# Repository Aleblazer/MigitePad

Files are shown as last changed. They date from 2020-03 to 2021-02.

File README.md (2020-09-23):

# MigitePad
## *__MigitePad!__* A Numpad/Nav Cluster with QMK Firmware/Kailh Hotswap/OLED/Rotary Encoder! 
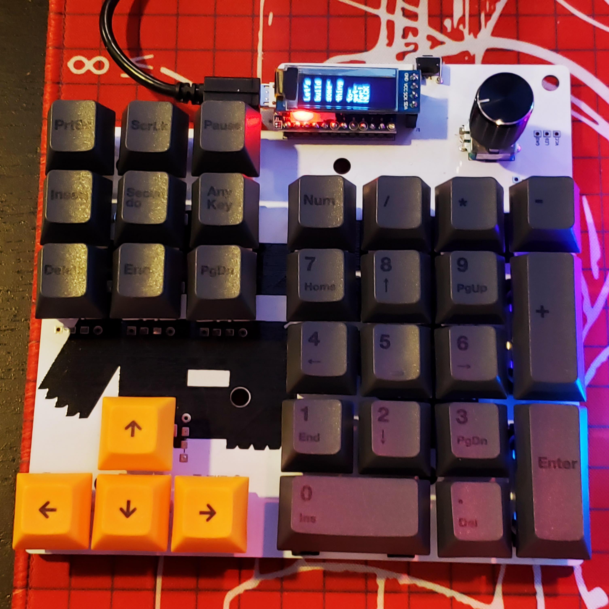
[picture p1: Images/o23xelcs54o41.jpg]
Built Board

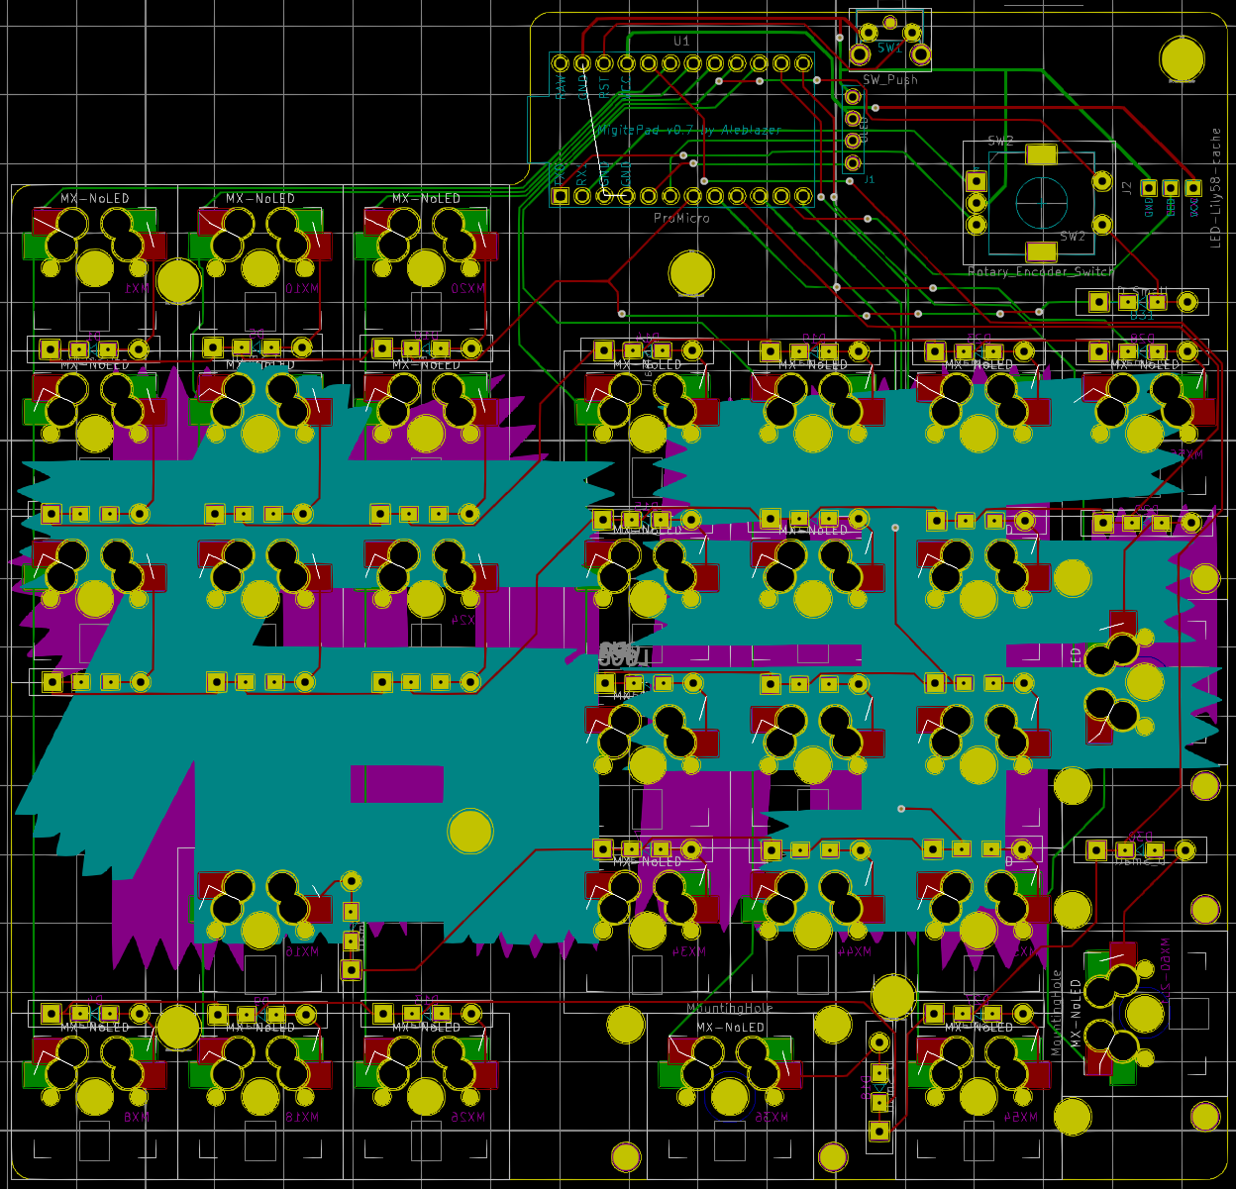
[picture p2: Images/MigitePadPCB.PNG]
PCB

Even reversable for you crazies who want a backwards Numpad!*
*OLED will need to be trace cut and bodged if you want it to work backwards

Materials needed:
* 30x Kailh Hotswap Sockets (Technically optional, hotswap through holes are plated)
* 31x 1N4148 or SOD-123F Diodes
* 30x MX style switches
* 1x MJTP1117 Reset Switch
* 1x Pro Micro or equivilant (Pro Micro chip side up for normal orientation, bottom side up for reversed.)
* 3x 2u stabilizers
* 1x EC11 Rotary Encoder
* 1x SSD1306 OLED (Optional)

For the 3D Printable Case:
* 6x 6mm M2 standoffs
* 12x M2 4mm or 5mm screws

OLED and Rotary Encoder code would need to be added to the end of your keymap.c. Still working on a more official OLED config. Example code borrowed and tested as working from the RoMac+, and is located in "QMK Keyboard Folder/migitepad/keymaps/default/keymap.c". Also encluded a default hex file in the QMK Keyboard Folder.

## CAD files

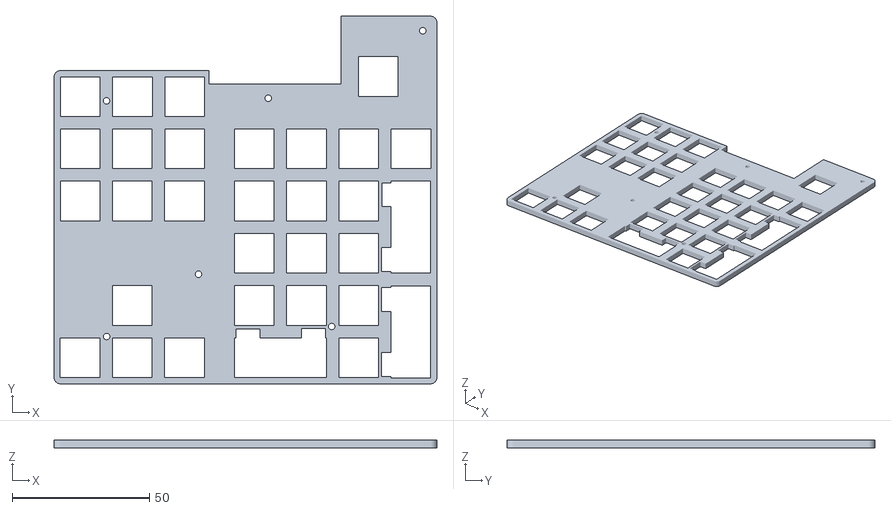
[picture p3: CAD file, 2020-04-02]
3D Printable Plate Files/MigitePad Top Plate v3.stl
139.7 x 134.1 x 3.00

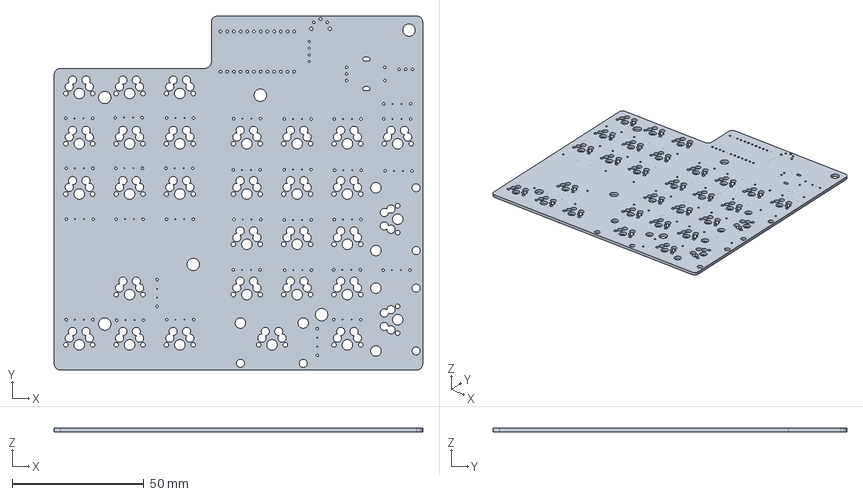
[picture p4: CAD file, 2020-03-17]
MigitePad.step
139.7 x 134.1 x 1.60 mm

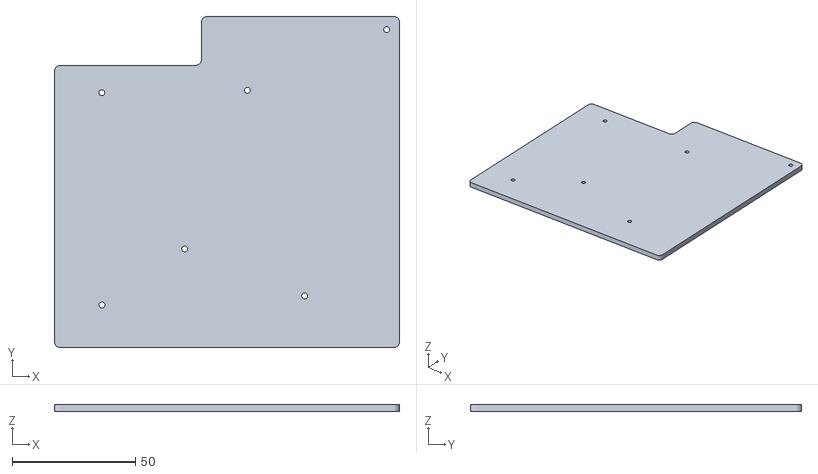
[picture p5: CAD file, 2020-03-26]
3D Printable Plate Files/MigitePad Bottom Plate.stl
139.7 x 134.1 x 3.00

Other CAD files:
3D Printable Plate Files/MigitePad Top Plate v2.stl
MigitePad.stl

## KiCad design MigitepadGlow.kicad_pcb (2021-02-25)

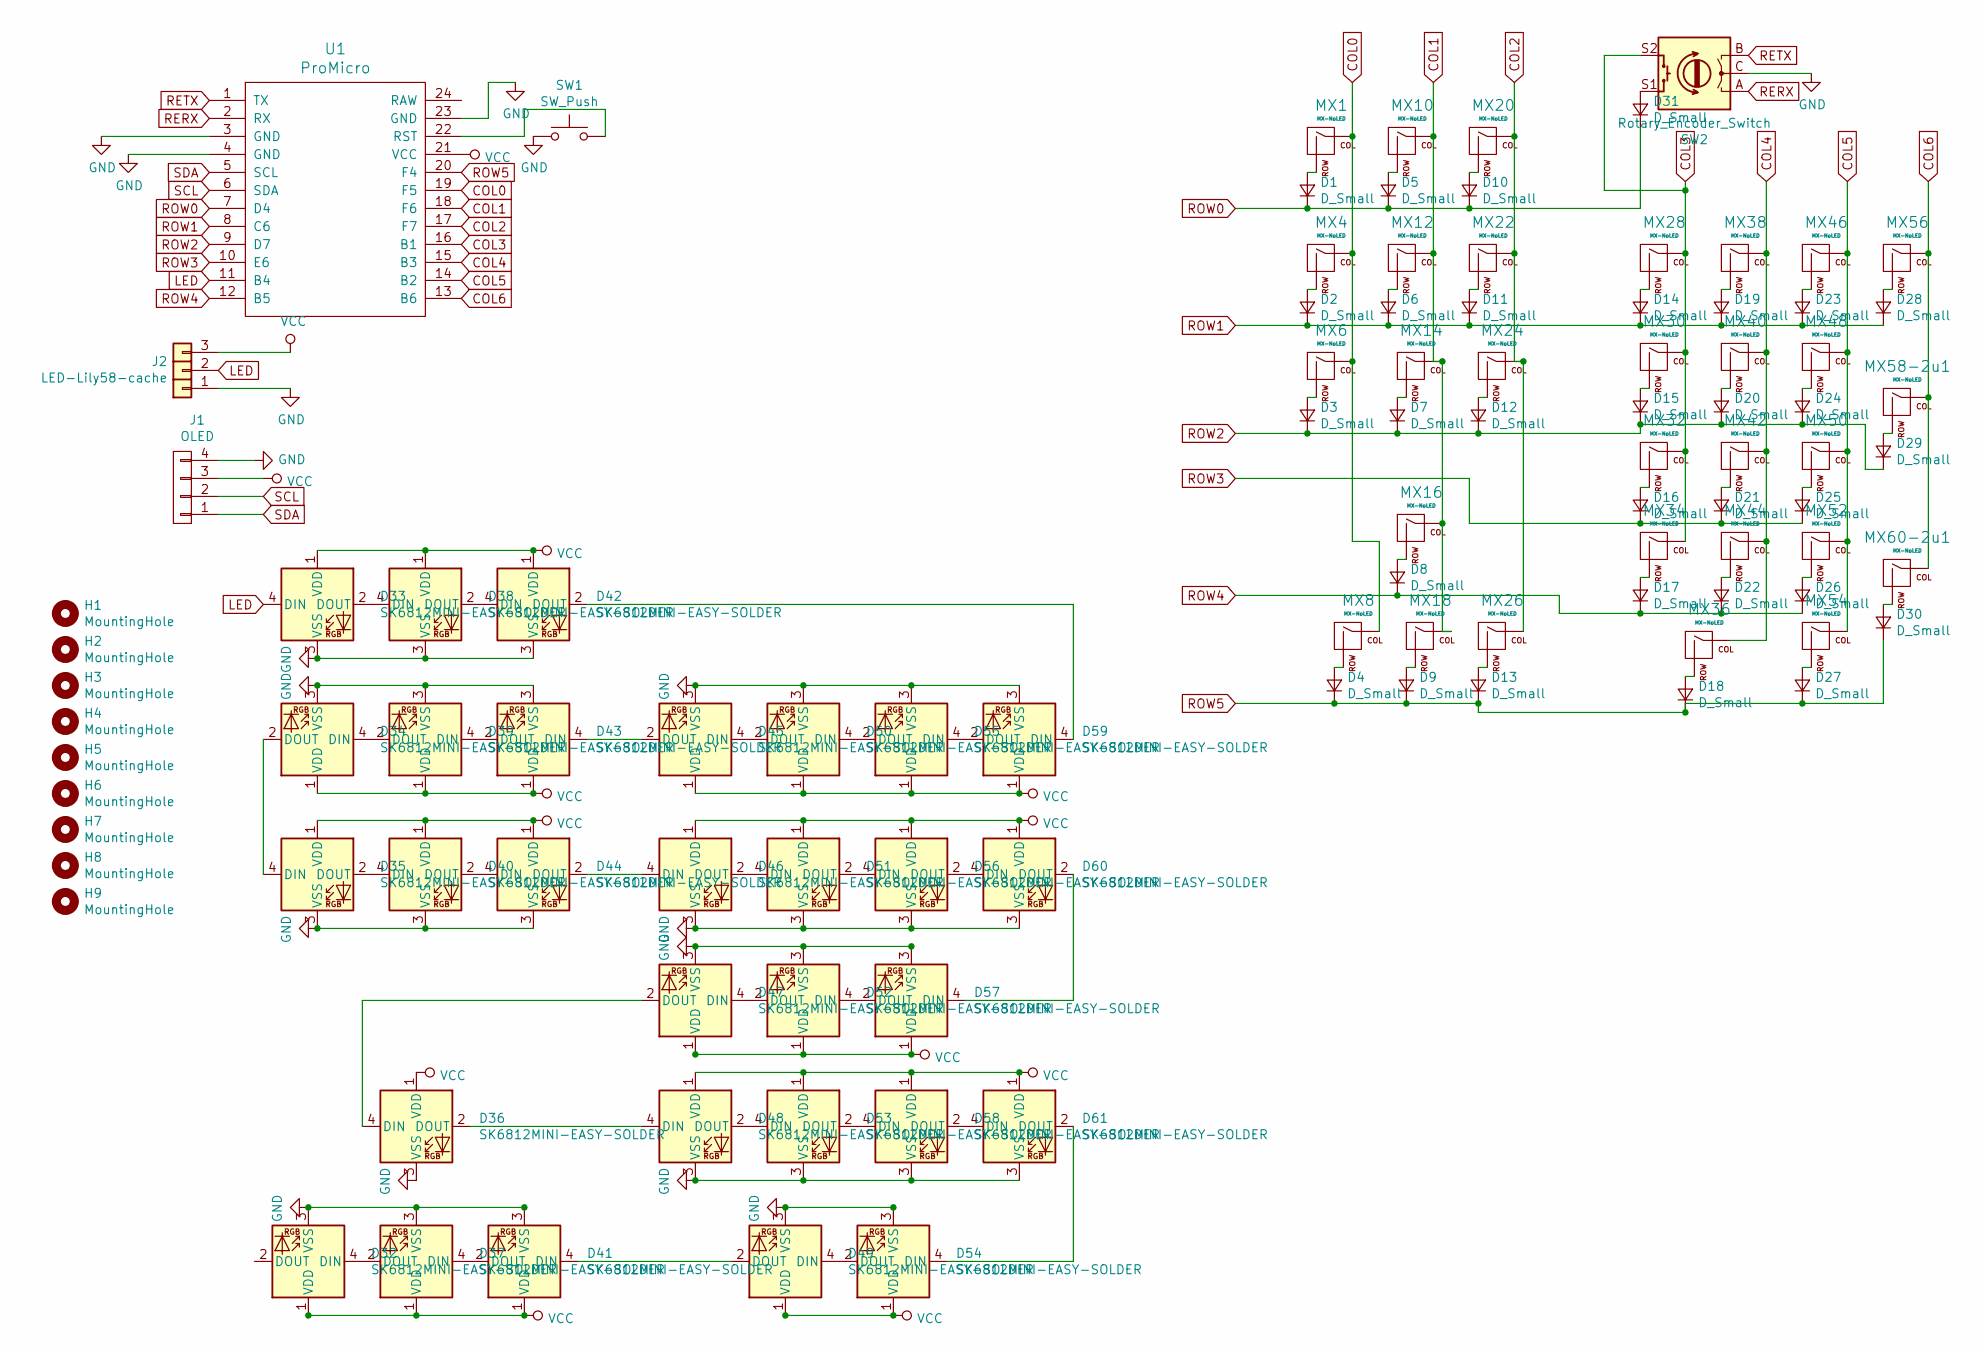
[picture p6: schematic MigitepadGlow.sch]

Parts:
D1, D2, D3, D4, D5, D6, D7, D8, D9, D10, D11, D12, D13, D14, D15, D16, D17, D18, D19, D20, D21, D22, D23, D24, D25, D26, D27, D28, D29, D30, D31: D_Small; Diode_TH_SOD123
D32, D33, D34, D35, D36, D37, D38, D39, D40, D41, D42, D43, D44, D45, D46, D47, D48, D49, D50, D51, D52, D53, D54, D55, D56, D57, D58, D59, D60, D61: SK6812MINI-EASY-SOLDER; YS-SK6812MINI-E
H1, H2, H3: MountingHole; Stabilizer_MX_2u
H4, H5, H6, H7, H8, H9: MountingHole; HOLE_M2_TH
J1: OLED; MY_SIL-4
J2: LED-Lily58-cache; LED
MX1, MX4, MX6, MX8, MX10, MX12, MX14, MX16, MX18, MX20, MX22, MX24, MX26, MX28, MX30, MX32, MX34, MX36, MX38, MX40, MX42, MX44, MX46, MX48, MX50, MX52, MX54, MX56, MX58-2u1, MX60-2u1: MX-NoLED; MXOnly-1U-Hotswap-Double-noled
SW1: SW_Push; SW_Tactile_SPST_Angled_MJTP1117
SW2: Rotary_Encoder_Switch; RotaryEncoder_EC11
U1: ProMicro

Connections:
COL0: MX1.1 (COL), MX4.1 (COL), MX6.1 (COL), MX8.1 (COL), U1.19 (F5)
COL1: MX10.1 (COL), MX12.1 (COL), MX14.1 (COL), MX16.1 (COL), MX18.1 (COL), U1.18 (F6)
COL2: MX20.1 (COL), MX22.1 (COL), MX24.1 (COL), MX26.1 (COL), U1.17 (F7)
COL3: MX28.1 (COL), MX30.1 (COL), MX32.1 (COL), MX34.1 (COL), SW2.S2, U1.16 (B1)
COL4: MX36.1 (COL), MX38.1 (COL), MX40.1 (COL), MX42.1 (COL), MX44.1 (COL), U1.15 (B3)
COL5: MX46.1 (COL), MX48.1 (COL), MX50.1 (COL), MX52.1 (COL), MX54.1 (COL), U1.14 (B2)
COL6: MX56.1 (COL), MX58-2u1.1 (COL), MX60-2u1.1 (COL), U1.13 (B6)
GND: D32.3 (VSS), D33.3 (VSS), D34.3 (VSS), D35.3 (VSS), D36.3 (VSS), D37.3 (VSS), D38.3 (VSS), D39.3 (VSS), D40.3 (VSS), D41.3 (VSS), D42.3 (VSS), D43.3 (VSS), D44.3 (VSS), D45.3 (VSS), D46.3 (VSS), D47.3 (VSS), D48.3 (VSS), D49.3 (VSS), D50.3 (VSS), D51.3 (VSS), D52.3 (VSS), D53.3 (VSS), D54.3 (VSS), D55.3 (VSS), D56.3 (VSS), D57.3 (VSS), D58.3 (VSS), D59.3 (VSS), D60.3 (VSS), D61.3 (VSS), J1.4, J2.1, SW1.1, SW2.C, U1.3 (GND), U1.4 (GND), U1.23 (GND)
LED: D33.4 (DIN), J2.2, U1.11 (B4)
unnamed: D1.2 (A), MX1.2 (ROW)
unnamed: D2.2 (A), MX4.2 (ROW)
unnamed: D3.2 (A), MX6.2 (ROW)
unnamed: D4.2 (A), MX8.2 (ROW)
unnamed: D5.2 (A), MX10.2 (ROW)
unnamed: D6.2 (A), MX12.2 (ROW)
unnamed: D7.2 (A), MX14.2 (ROW)
unnamed: D8.2 (A), MX16.2 (ROW)
unnamed: D9.2 (A), MX18.2 (ROW)
unnamed: D10.2 (A), MX20.2 (ROW)
unnamed: D11.2 (A), MX22.2 (ROW)
unnamed: D12.2 (A), MX24.2 (ROW)
unnamed: D13.2 (A), MX26.2 (ROW)
unnamed: D14.2 (A), MX28.2 (ROW)
unnamed: D15.2 (A), MX30.2 (ROW)
unnamed: D16.2 (A), MX32.2 (ROW)
unnamed: D17.2 (A), MX34.2 (ROW)
unnamed: D18.2 (A), MX36.2 (ROW)
unnamed: D19.2 (A), MX38.2 (ROW)
unnamed: D20.2 (A), MX40.2 (ROW)
unnamed: D21.2 (A), MX42.2 (ROW)
unnamed: D22.2 (A), MX44.2 (ROW)
unnamed: D23.2 (A), MX46.2 (ROW)
unnamed: D24.2 (A), MX48.2 (ROW)
unnamed: D25.2 (A), MX50.2 (ROW)
unnamed: D26.2 (A), MX52.2 (ROW)
unnamed: D27.2 (A), MX54.2 (ROW)
unnamed: D28.2 (A), MX56.2 (ROW)
unnamed: D29.2 (A), MX58-2u1.2 (ROW)
unnamed: D30.2 (A), MX60-2u1.2 (ROW)
unnamed: D31.2 (A), SW2.S1
unnamed: D32.4 (DIN), D37.2 (DOUT)
unnamed: D33.2 (DOUT), D38.4 (DIN)
unnamed: D34.2 (DOUT), D35.4 (DIN)
unnamed: D34.4 (DIN), D39.2 (DOUT)
unnamed: D35.2 (DOUT), D40.4 (DIN)
unnamed: D36.2 (DOUT), D48.4 (DIN)
unnamed: D36.4 (DIN), D47.2 (DOUT)
unnamed: D37.4 (DIN), D41.2 (DOUT)
unnamed: D38.2 (DOUT), D42.4 (DIN)
unnamed: D39.4 (DIN), D43.2 (DOUT)
unnamed: D40.2 (DOUT), D44.4 (DIN)
unnamed: D41.4 (DIN), D49.2 (DOUT)
unnamed: D42.2 (DOUT), D59.4 (DIN)
unnamed: D43.4 (DIN), D45.2 (DOUT)
unnamed: D44.2 (DOUT), D46.4 (DIN)
unnamed: D45.4 (DIN), D50.2 (DOUT)
unnamed: D46.2 (DOUT), D51.4 (DIN)
unnamed: D47.4 (DIN), D52.2 (DOUT)
unnamed: D48.2 (DOUT), D53.4 (DIN)
unnamed: D49.4 (DIN), D54.2 (DOUT)
unnamed: D50.4 (DIN), D55.2 (DOUT)
unnamed: D51.2 (DOUT), D56.4 (DIN)
unnamed: D52.4 (DIN), D57.2 (DOUT)
unnamed: D53.2 (DOUT), D58.4 (DIN)
unnamed: D54.4 (DIN), D61.2 (DOUT)
unnamed: D55.4 (DIN), D59.2 (DOUT)
unnamed: D56.2 (DOUT), D60.4 (DIN)
unnamed: D57.4 (DIN), D60.2 (DOUT)
unnamed: D58.2 (DOUT), D61.4 (DIN)
unnamed: SW1.2, U1.22 (RST)
RERX: SW2.A, U1.2 (RX)
RETX: SW2.B, U1.1 (TX)
ROW0: D1.1 (K), D5.1 (K), D10.1 (K), D31.1 (K), U1.7 (D4)
ROW1: D2.1 (K), D6.1 (K), D11.1 (K), D14.1 (K), D19.1 (K), D23.1 (K), D28.1 (K), U1.8 (C6)
ROW2: D3.1 (K), D7.1 (K), D12.1 (K), D15.1 (K), D20.1 (K), D24.1 (K), D29.1 (K), U1.9 (D7)
ROW3: D16.1 (K), D21.1 (K), D25.1 (K), U1.10 (E6)
ROW4: D8.1 (K), D17.1 (K), D22.1 (K), D26.1 (K), U1.12 (B5)
ROW5: D4.1 (K), D9.1 (K), D13.1 (K), D18.1 (K), D27.1 (K), D30.1 (K), U1.20 (F4)
SCL: J1.2, U1.6 (SDA)
SDA: J1.1, U1.5 (SCL)
VCC: D32.1 (VDD), D33.1 (VDD), D34.1 (VDD), D35.1 (VDD), D36.1 (VDD), D37.1 (VDD), D38.1 (VDD), D39.1 (VDD), D40.1 (VDD), D41.1 (VDD), D42.1 (VDD), D43.1 (VDD), D44.1 (VDD), D45.1 (VDD), D46.1 (VDD), D47.1 (VDD), D48.1 (VDD), D49.1 (VDD), D50.1 (VDD), D51.1 (VDD), D52.1 (VDD), D53.1 (VDD), D54.1 (VDD), D55.1 (VDD), D56.1 (VDD), D57.1 (VDD), D58.1 (VDD), D59.1 (VDD), D60.1 (VDD), D61.1 (VDD), J1.3, J2.3, U1.21 (VCC)

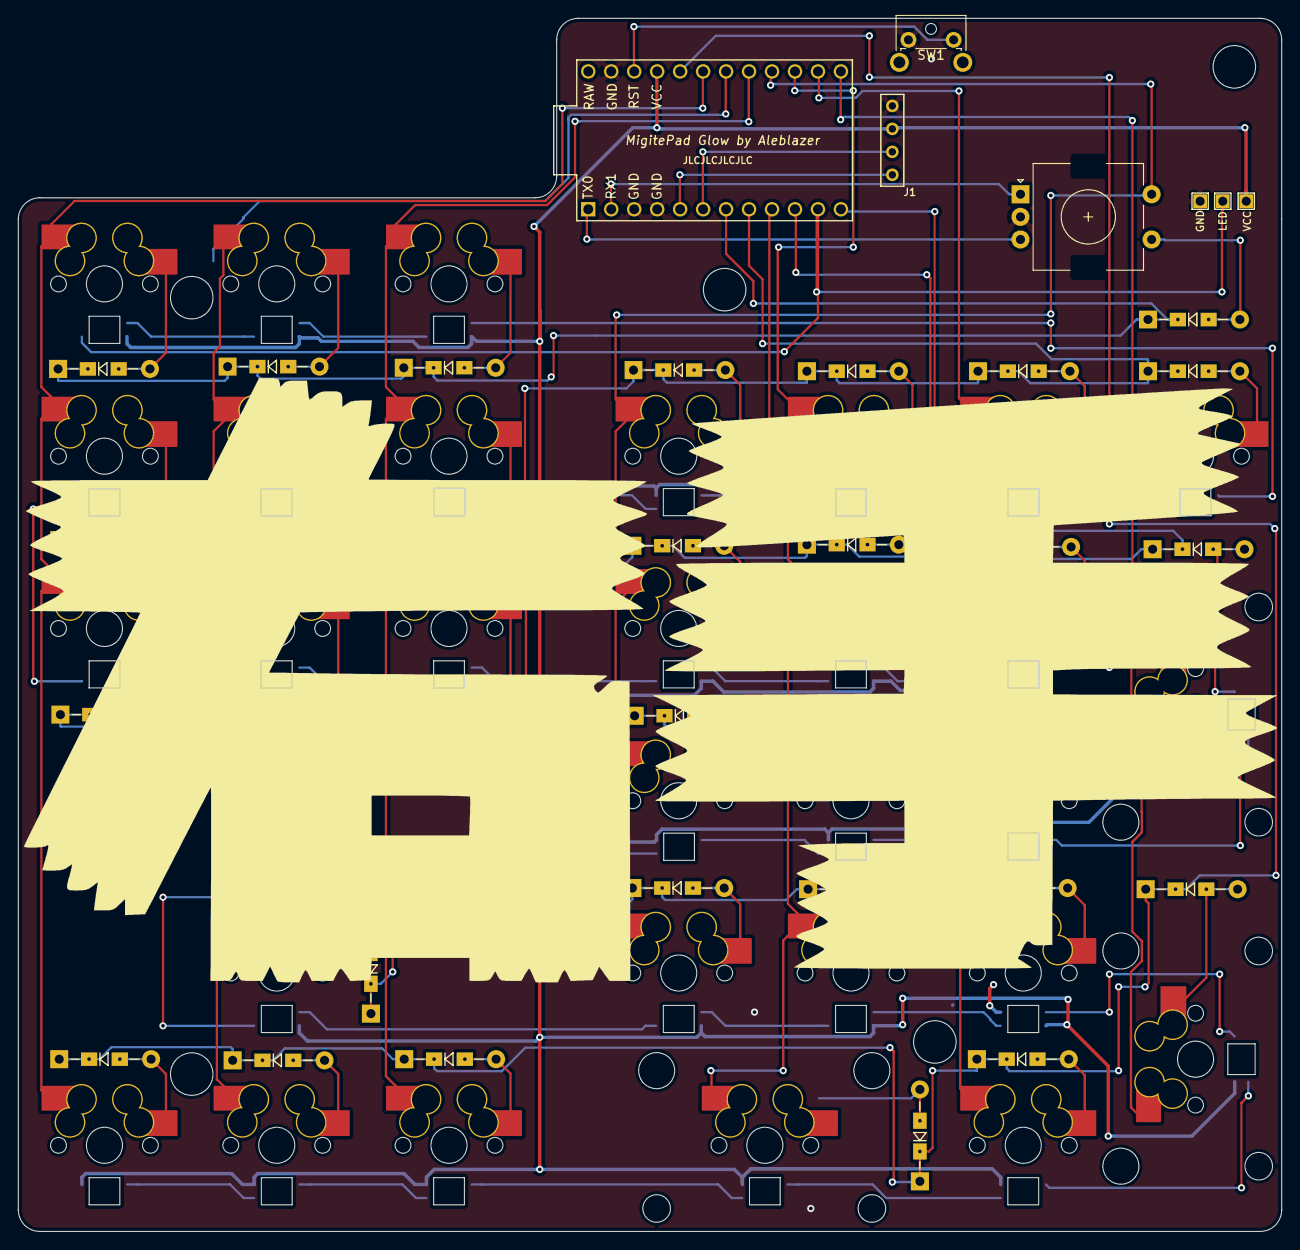
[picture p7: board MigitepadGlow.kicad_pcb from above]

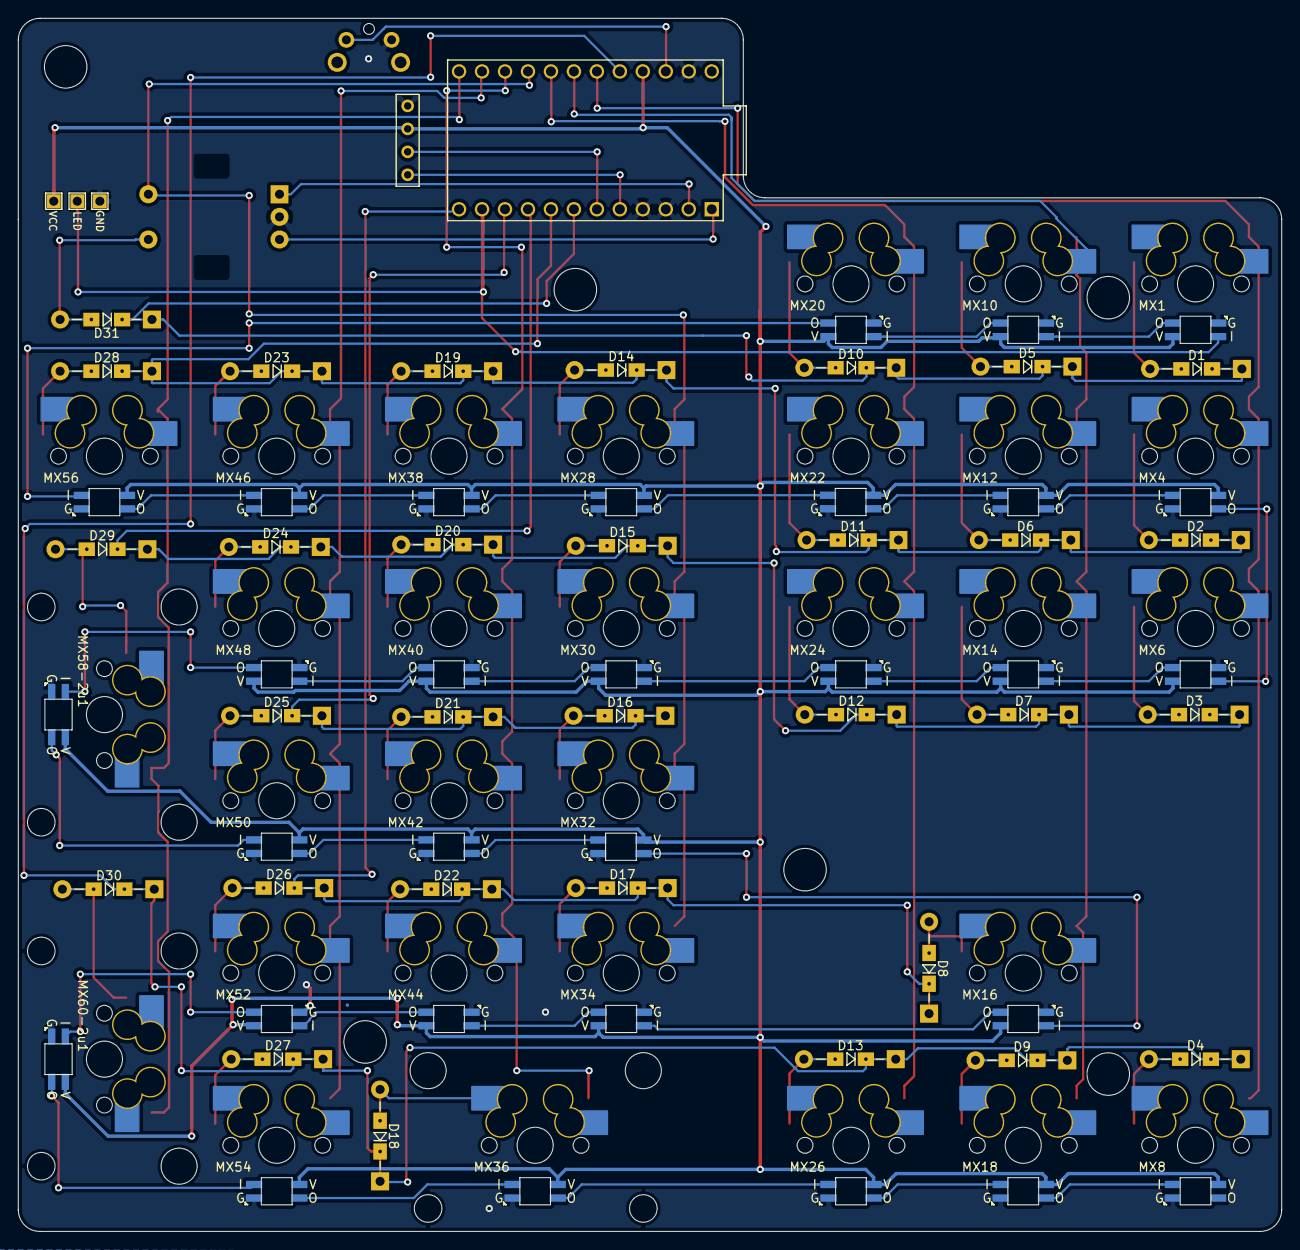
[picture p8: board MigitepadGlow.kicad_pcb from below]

Board: 2 copper layers, 139.7 x 134.1 mm, 105 parts (60 on the bottom side), 81 nets.

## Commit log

2020-02-24 Added Footprints
2020-03-02 Changed to ProMicro
    [MigitePad.kicad_pcb, MigitePad.sch]
2020-03-02 Removed GND fill
    [MigitePad.kicad_pcb]
2020-03-02 Added OLED header
    [MigitePad.kicad_pcb, MigitePad.sch]
2020-03-03 Split into v05(Standard) and v07(Kailh Hotswap)
    [MigitePad.kicad_pcb, MigitePad.sch]
2020-03-07 Changed Footprints
    [MigitePad-B_Cu.gbl, MigitePad-B_Mask.gbs, MigitePad-B_SilkS.gbo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]
2020-03-08 Added Rotary Encoder
    [MigitePad-B_Cu.gbl, MigitePad-B_Mask.gbs, MigitePad-B_SilkS.gbo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]
2020-03-09 Rewired Encoder
    [MigitePad.kicad_pcb, MigitePad.sch]
2020-03-14 Gerbers and final touches
    [MigitePad-B_Cu.gbl, MigitePad-B_Mask.gbs, MigitePad-B_SilkS.gbo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]
2020-03-17 Corrected Col1 Trace
    [MigitePad.kicad_pcb, MigitePad.step, MigitePad.stl]
2020-03-26 Removed old Gerbers, fixed more traces
    [MigitePad-B_Cu.gbl, MigitePad-B_Mask.gbs, MigitePad-B_SilkS.gbo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]
2020-03-26 Added 3D printable plates
    [MigitePad Bottom Plate.stl, MigitePad Top Plate.stl]
2020-03-27 Corrected stab spacing
    [MigitePad Top Plate v2.stl, MigitePad Top Plate.stl]
2020-04-02 Updated Gerbers and README.md
    [MigitePad-B_Cu.gbl, MigitePad-B_Mask.gbs, MigitePad-B_SilkS.gbo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]
2020-04-02 Added QMK firmware folder and default Pro Micro hex file
    [MigitePad Top Plate v3.stl]
2020-09-23 Added Migitepad Glow
    Added SKMini-E LEDs
    [MigitepadGlow.kicad_pcb, MigitepadGlow.sch]
2021-02-25 MigitePadGlow Final touches
    [MigitePad-B_Cu.gbl, MigitePad-B_Mask.gbs, MigitePad-B_SilkS.gbo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]
